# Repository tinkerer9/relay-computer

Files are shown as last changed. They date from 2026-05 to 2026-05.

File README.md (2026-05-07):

# Relay Computer
A relay computer that adds or subtracts two 4-bit numbers made for a Capstone project

## How to use
Power the computer with a 5V through the barrel jack on the top-right.

There are nine switches on the bottom left&mdash;these are the inputs.
The four on the top are the A3-A0 inputs, and the four on the bottom are the B3-B0 inputs.

On the the switch on the middle-right is the additon-subtraction selector.
Switch it up to add the two numbers, and down to subtract them.

## Bill of materials
Here is the BOM (bill of materials) for one of the computer, with links.
Prices are included (shipping not included) but always subject to change.

| Item | Variant | Quantity | Link | Price |
| :-: | :-: | :-: | :-: | :-: |
| Relays *(100x)* | SRD-05VDC-SLC | 20 | [AliExpress](https://www.aliexpress.us/item/3256805988664644.html) | $19.27 |
| Diodes *(100x)* | 1N4007 | 28 | [Amazon](https://www.amazon.com/dp/B0FC2CQF24) | $5.99 |
| LEDs | *red, 5mm* | 33 | | |
| Switches *(10x)* | MTS-102 | 9 | [Amazon](https://www.amazon.com/dp/B0799HC3VY) | $7.99 |
| Barrel Jack | *5.5mm OD* | 1 | | |
| Resistors | 220&ohm; | 33 | | |
| PCB *(5x)* | | 1 | *see [how to order](#how-to-order)* | $15.80 |
| **Total** | | **125** | | **$49.05** |

## How to order
Head to [JLCPCB](https://cart.jlcpcb.com/quote?stencilLayer=2&stencilWidth=140&stencilLength=210&plateType=1) and upload the gerber file at [`production.zip`](https://github.com/tinkerer9/relay-computer/raw/refs/heads/main/production.zip).

Use the default options for customizing your order.
Use this table for reference:

| Option | Selection |
| :-: | :-: |
| Base Material | FR-4 |
| Layers | 2 |
| Dimensions | 210 * 140 mm |
| PCB Qty | *you choose* |
| Product Type | Industrial/Consumer electronics |
| PCB Thickness | 1.6mm |
| PCB Color | *you choose* |

Select a build time and add the PCB to your cart.

For my order, the 5 PCBs costed **$15.80** and the shipping costed **&approx;$30**, plus tarrifs.
I ended up paying **&approx;$50**.
These prices are subject to change.

## Questions
For any questions about this project, feel free to create a [new issue](https://github.com/tinkerer9/relay-computer/issues/new) on this repository.

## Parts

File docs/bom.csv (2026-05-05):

Reference | Qty | Value | Footprint
D1-D4;D9-D16;D21-D24;D29-D36;D41-D44 | 28 | 1N4007 | Diode_THT:D_DO-41_SOD81_P7.62mm_Horizontal
D5-D8;D17-D20;D25-D28;D37-D40;D45-D52;D54-D62 | 33 | LED | LED_THT:LED_D5.0mm
H1-H4 | 4 | MountingHole_Pad | MountingHole:MountingHole_4.3mm_M4_Pad
J1 | 1 | Barrel_Jack_Switch | Connector_BarrelJack:BarrelJack_Horizontal
K1-K20 | 20 | SANYOU_SRD_Form_C | Relay_THT:Relay_SPDT_SANYOU_SRD_Series_Form_C
R1-R24;R26-R34 | 33 | 220 | Resistor_THT:R_Axial_DIN0207_L6.3mm_D2.5mm_P10.16mm_Horizontal
SW1-SW9 | 9 | SW_SPDT | Toggle_Switch:MTS-102

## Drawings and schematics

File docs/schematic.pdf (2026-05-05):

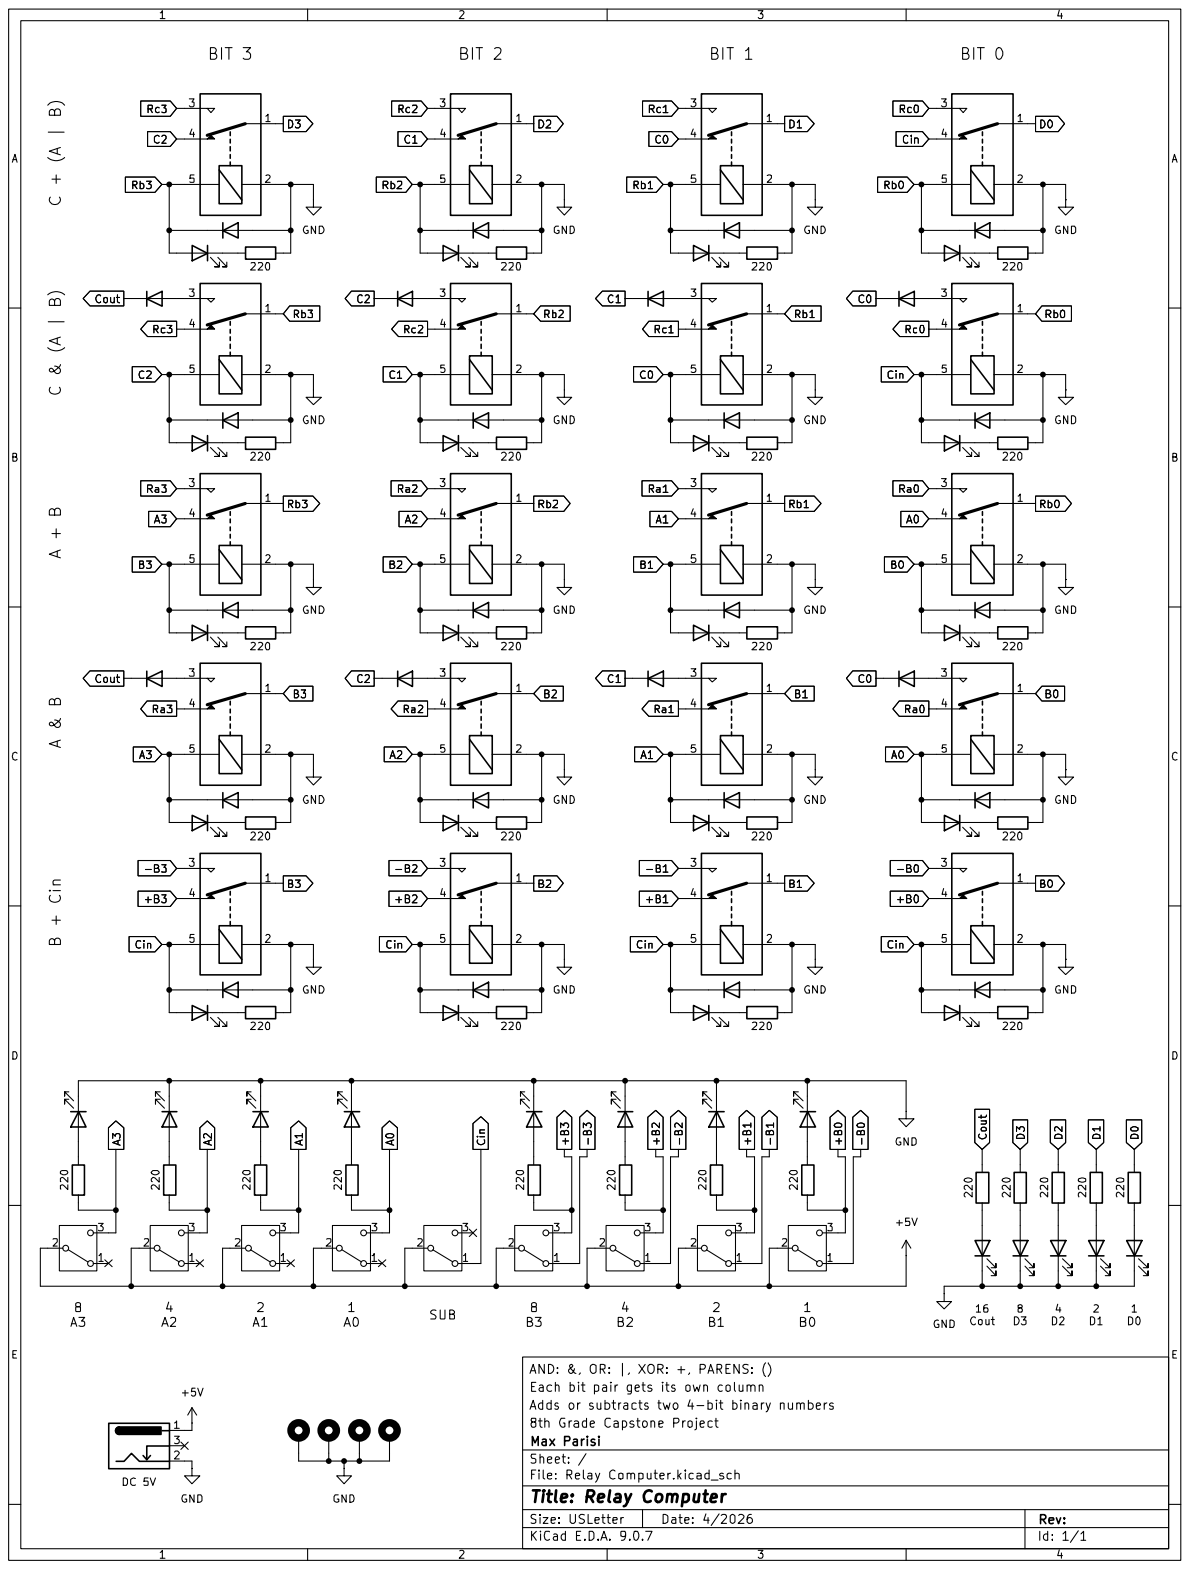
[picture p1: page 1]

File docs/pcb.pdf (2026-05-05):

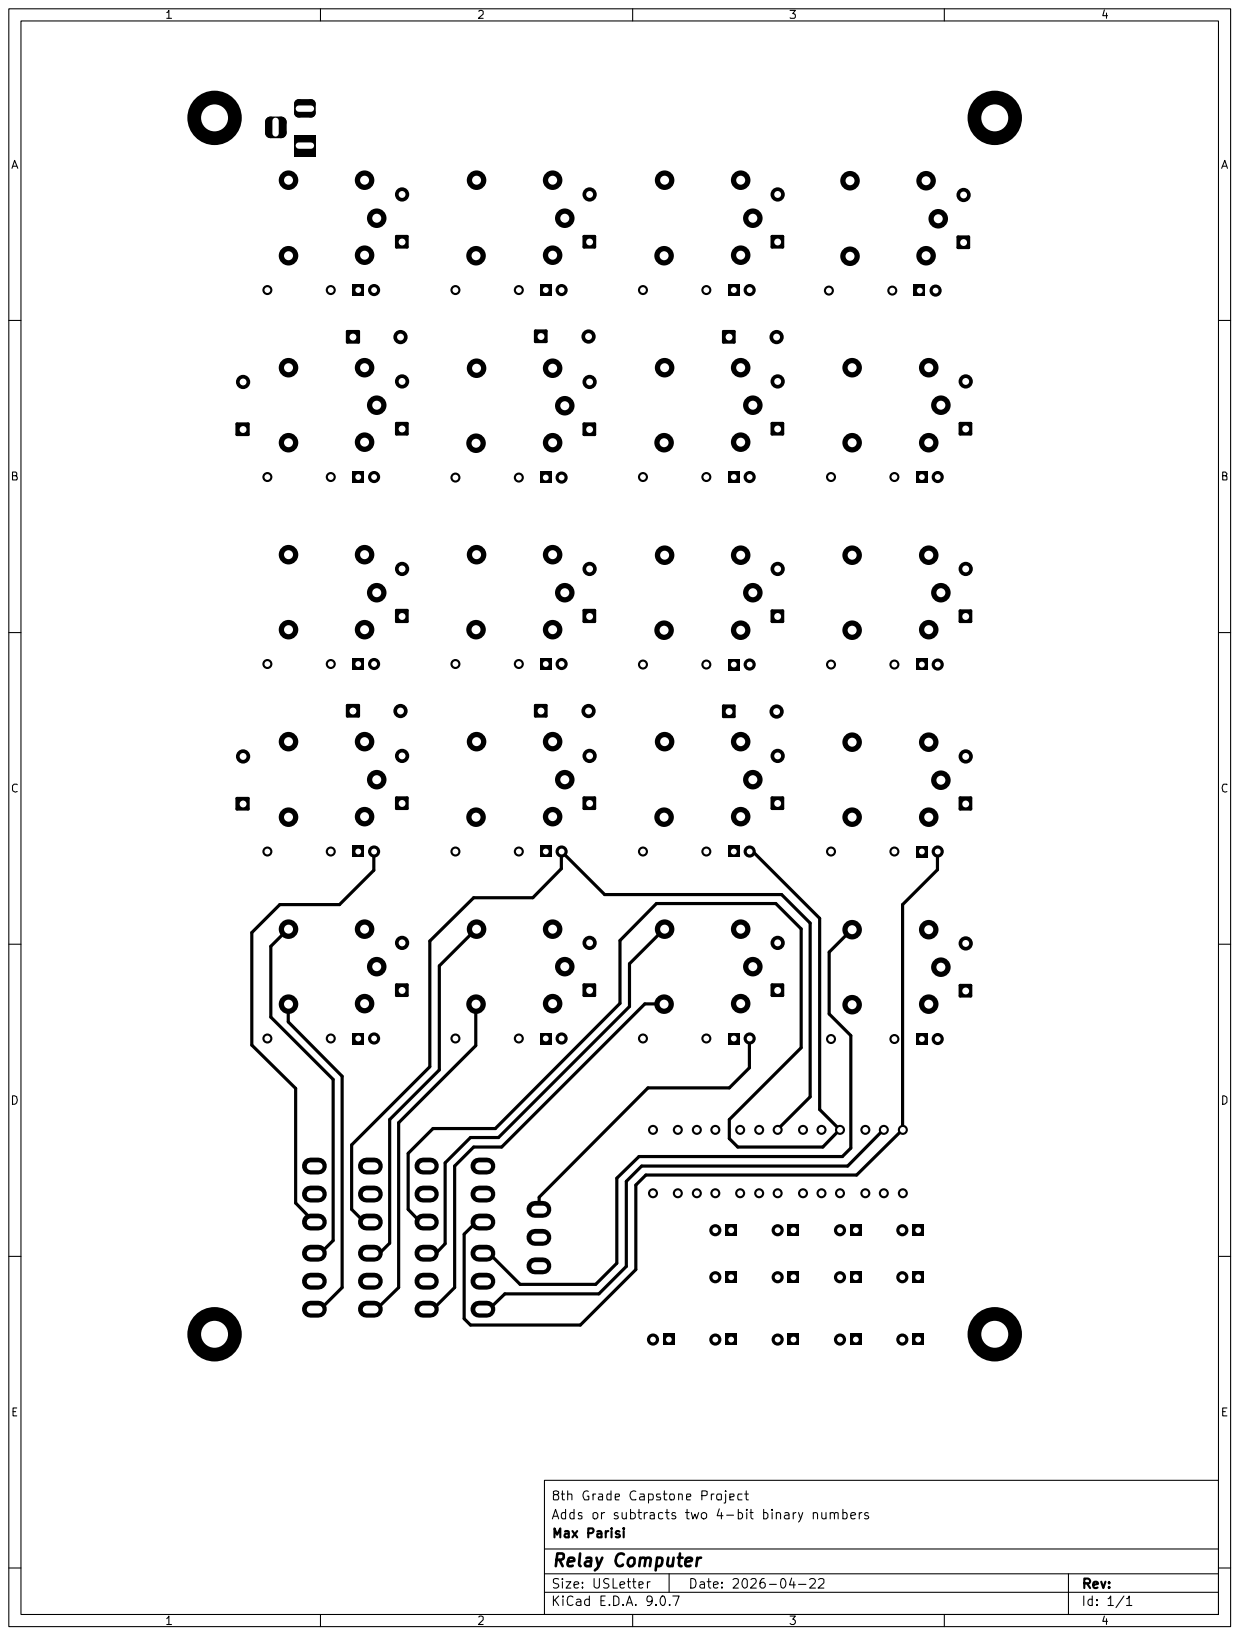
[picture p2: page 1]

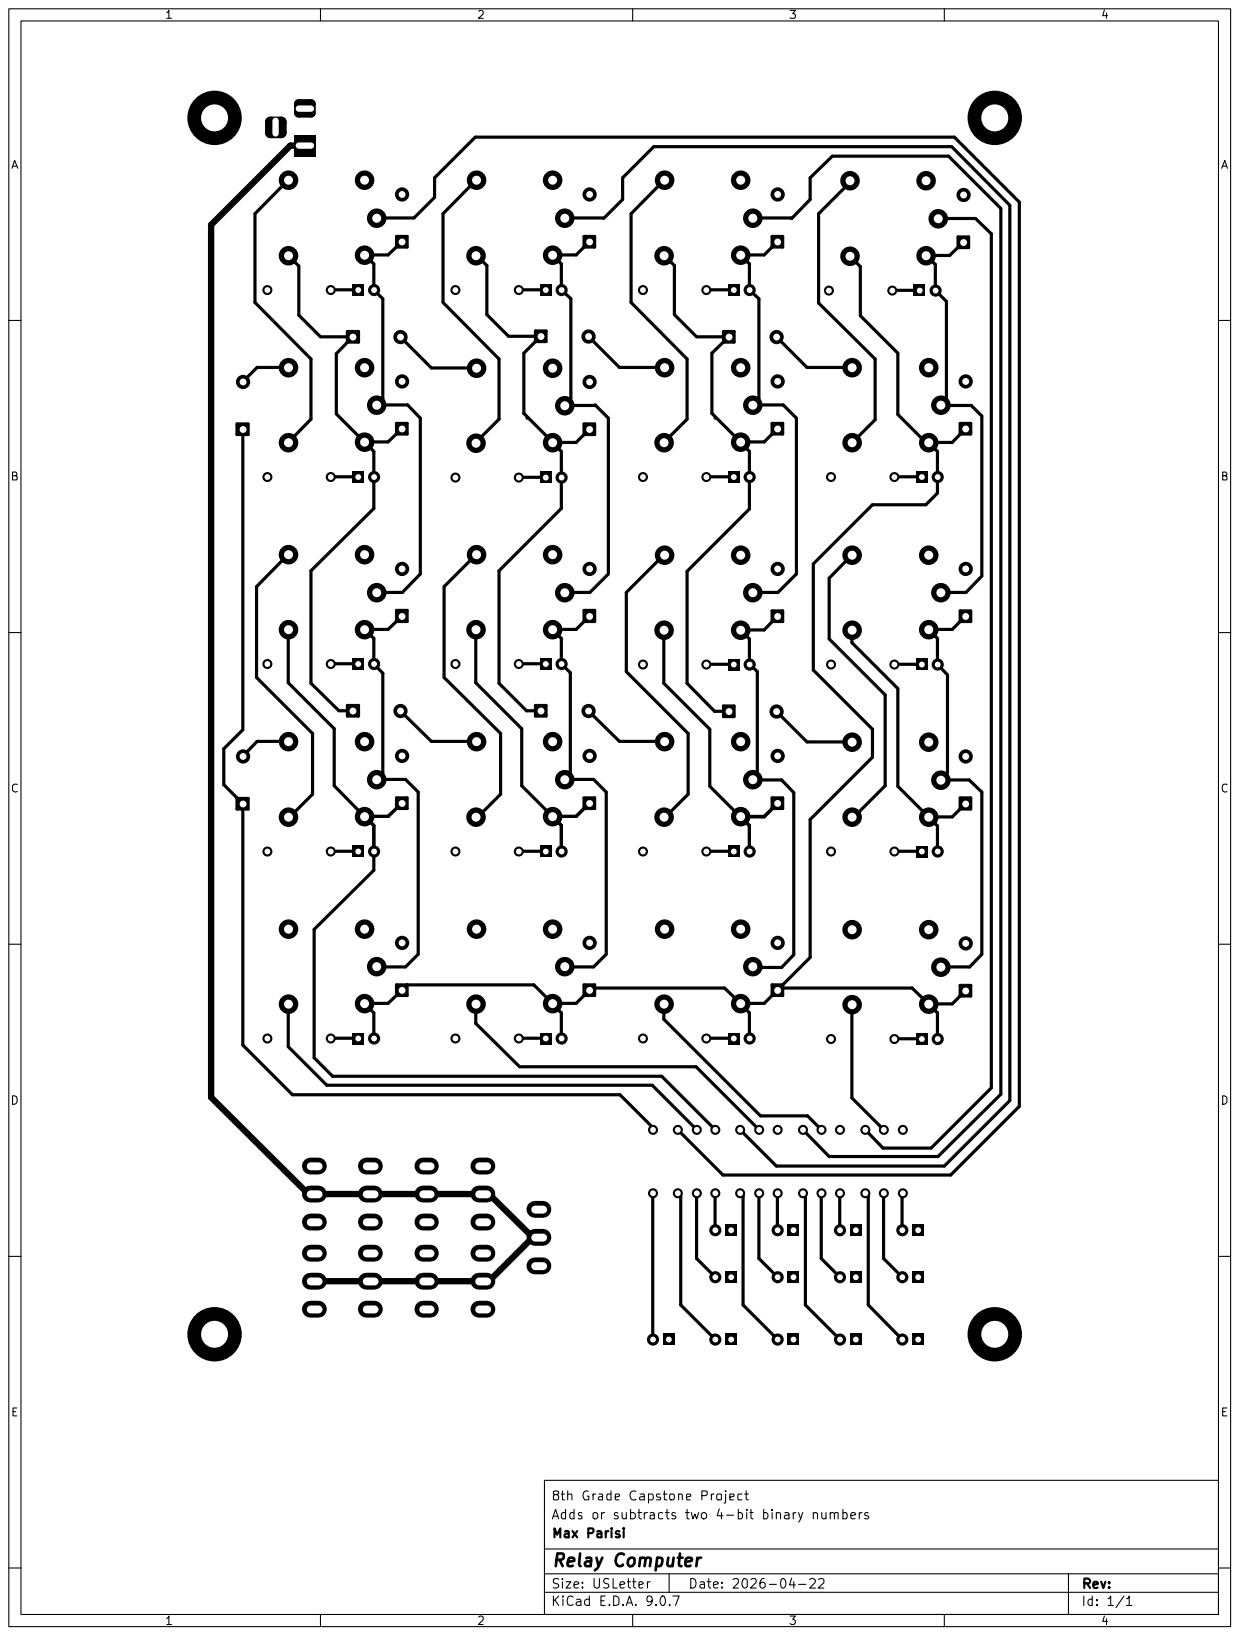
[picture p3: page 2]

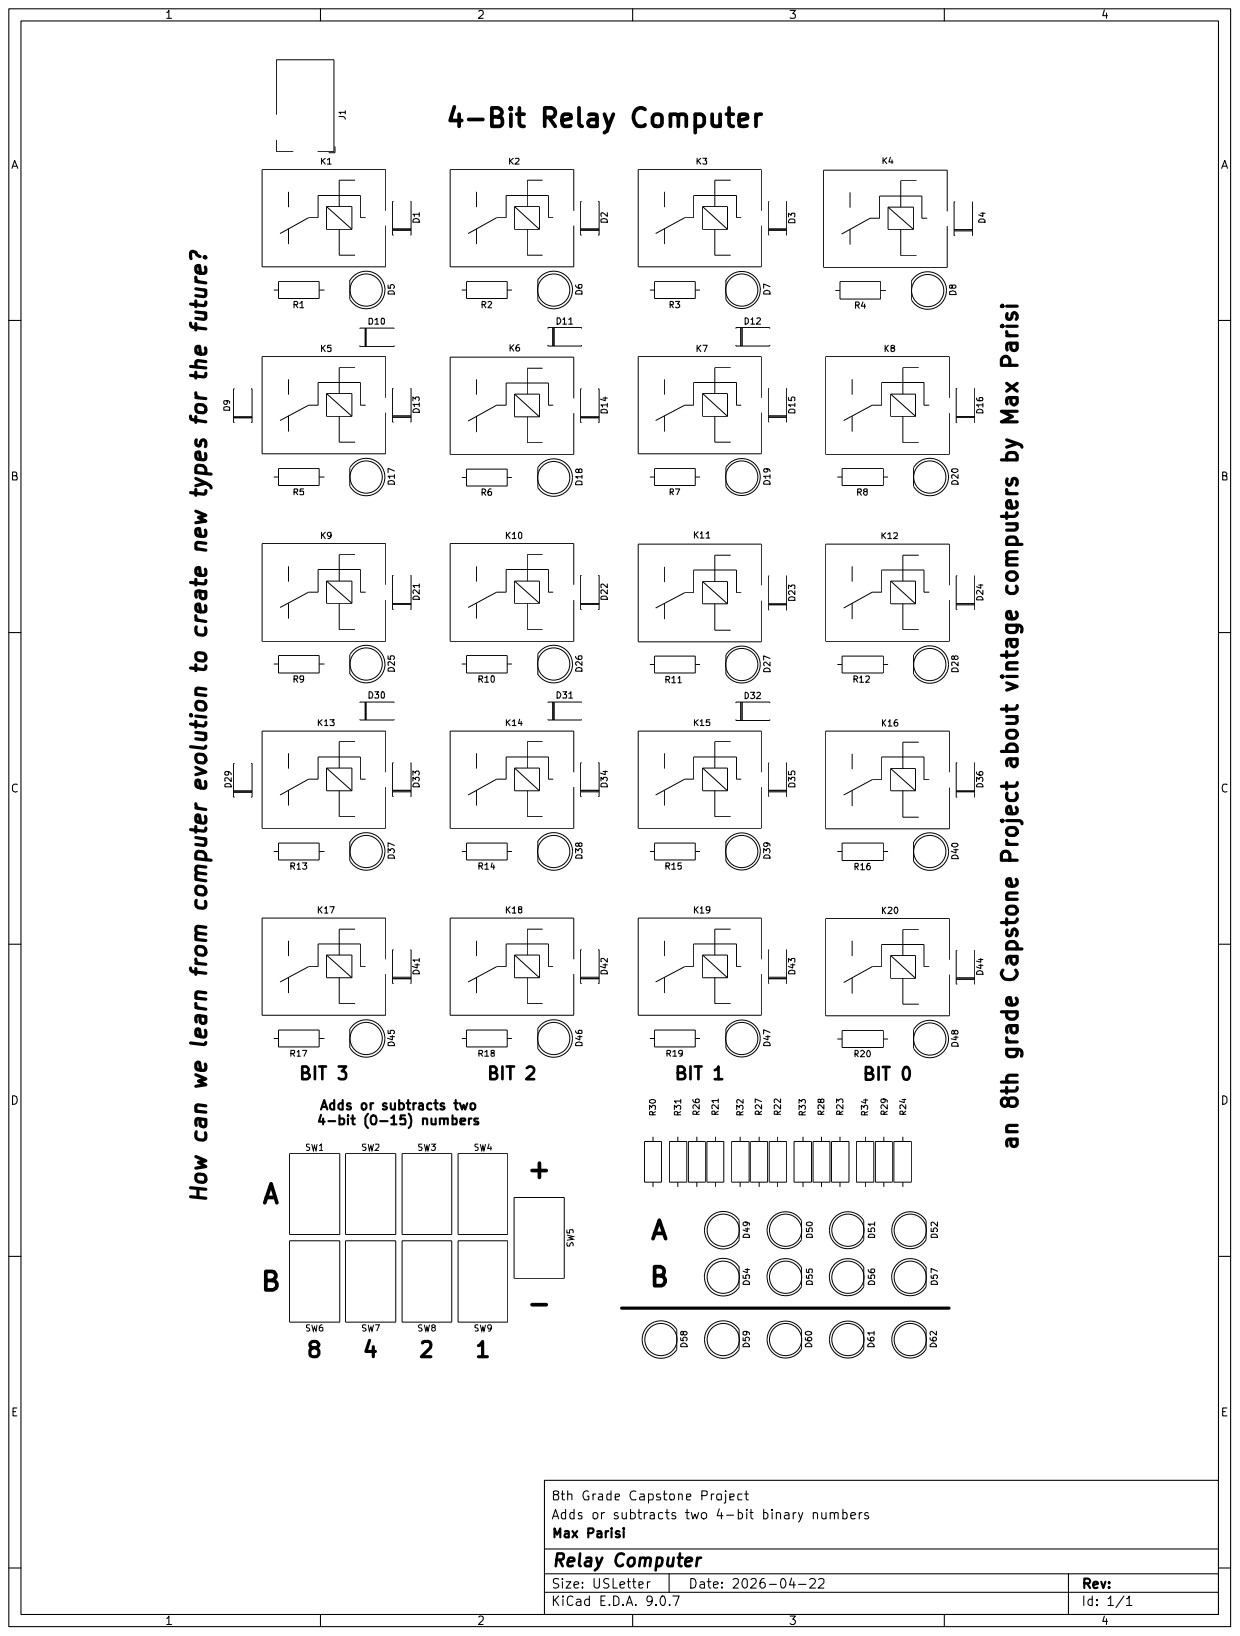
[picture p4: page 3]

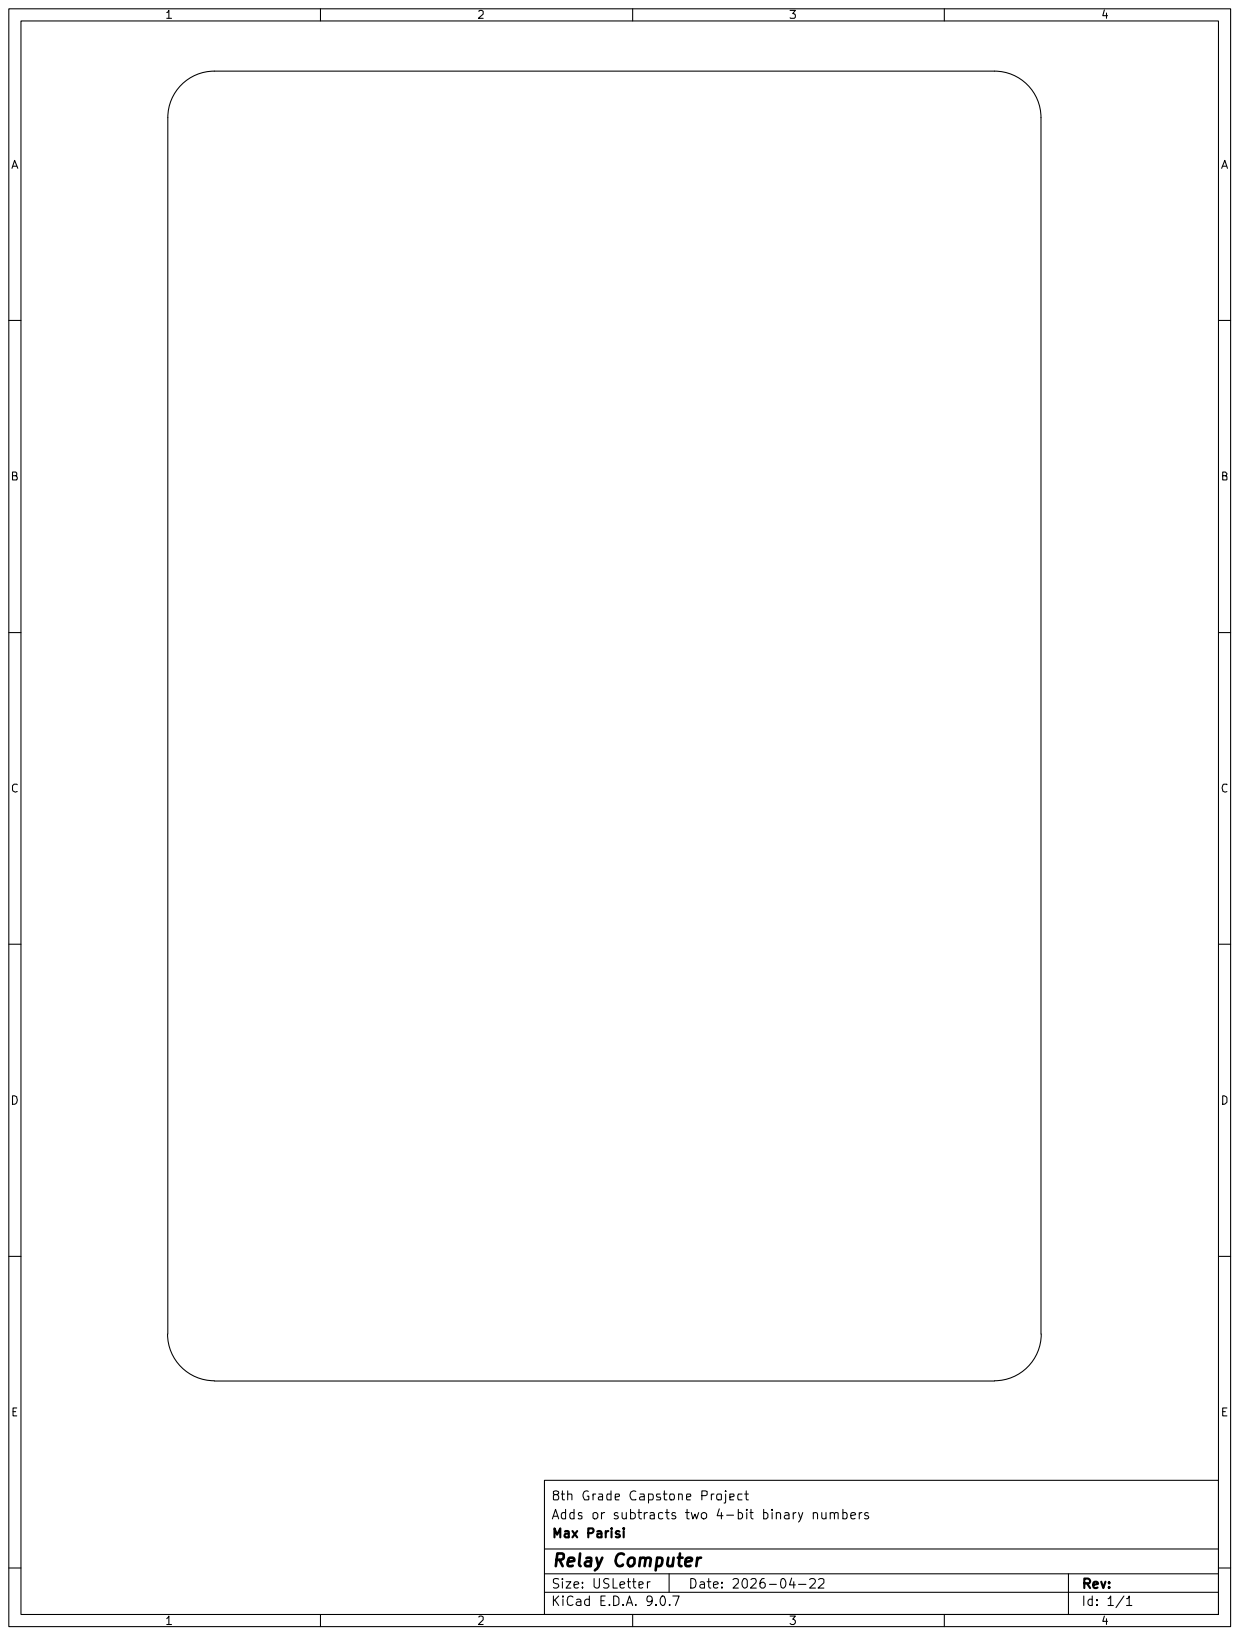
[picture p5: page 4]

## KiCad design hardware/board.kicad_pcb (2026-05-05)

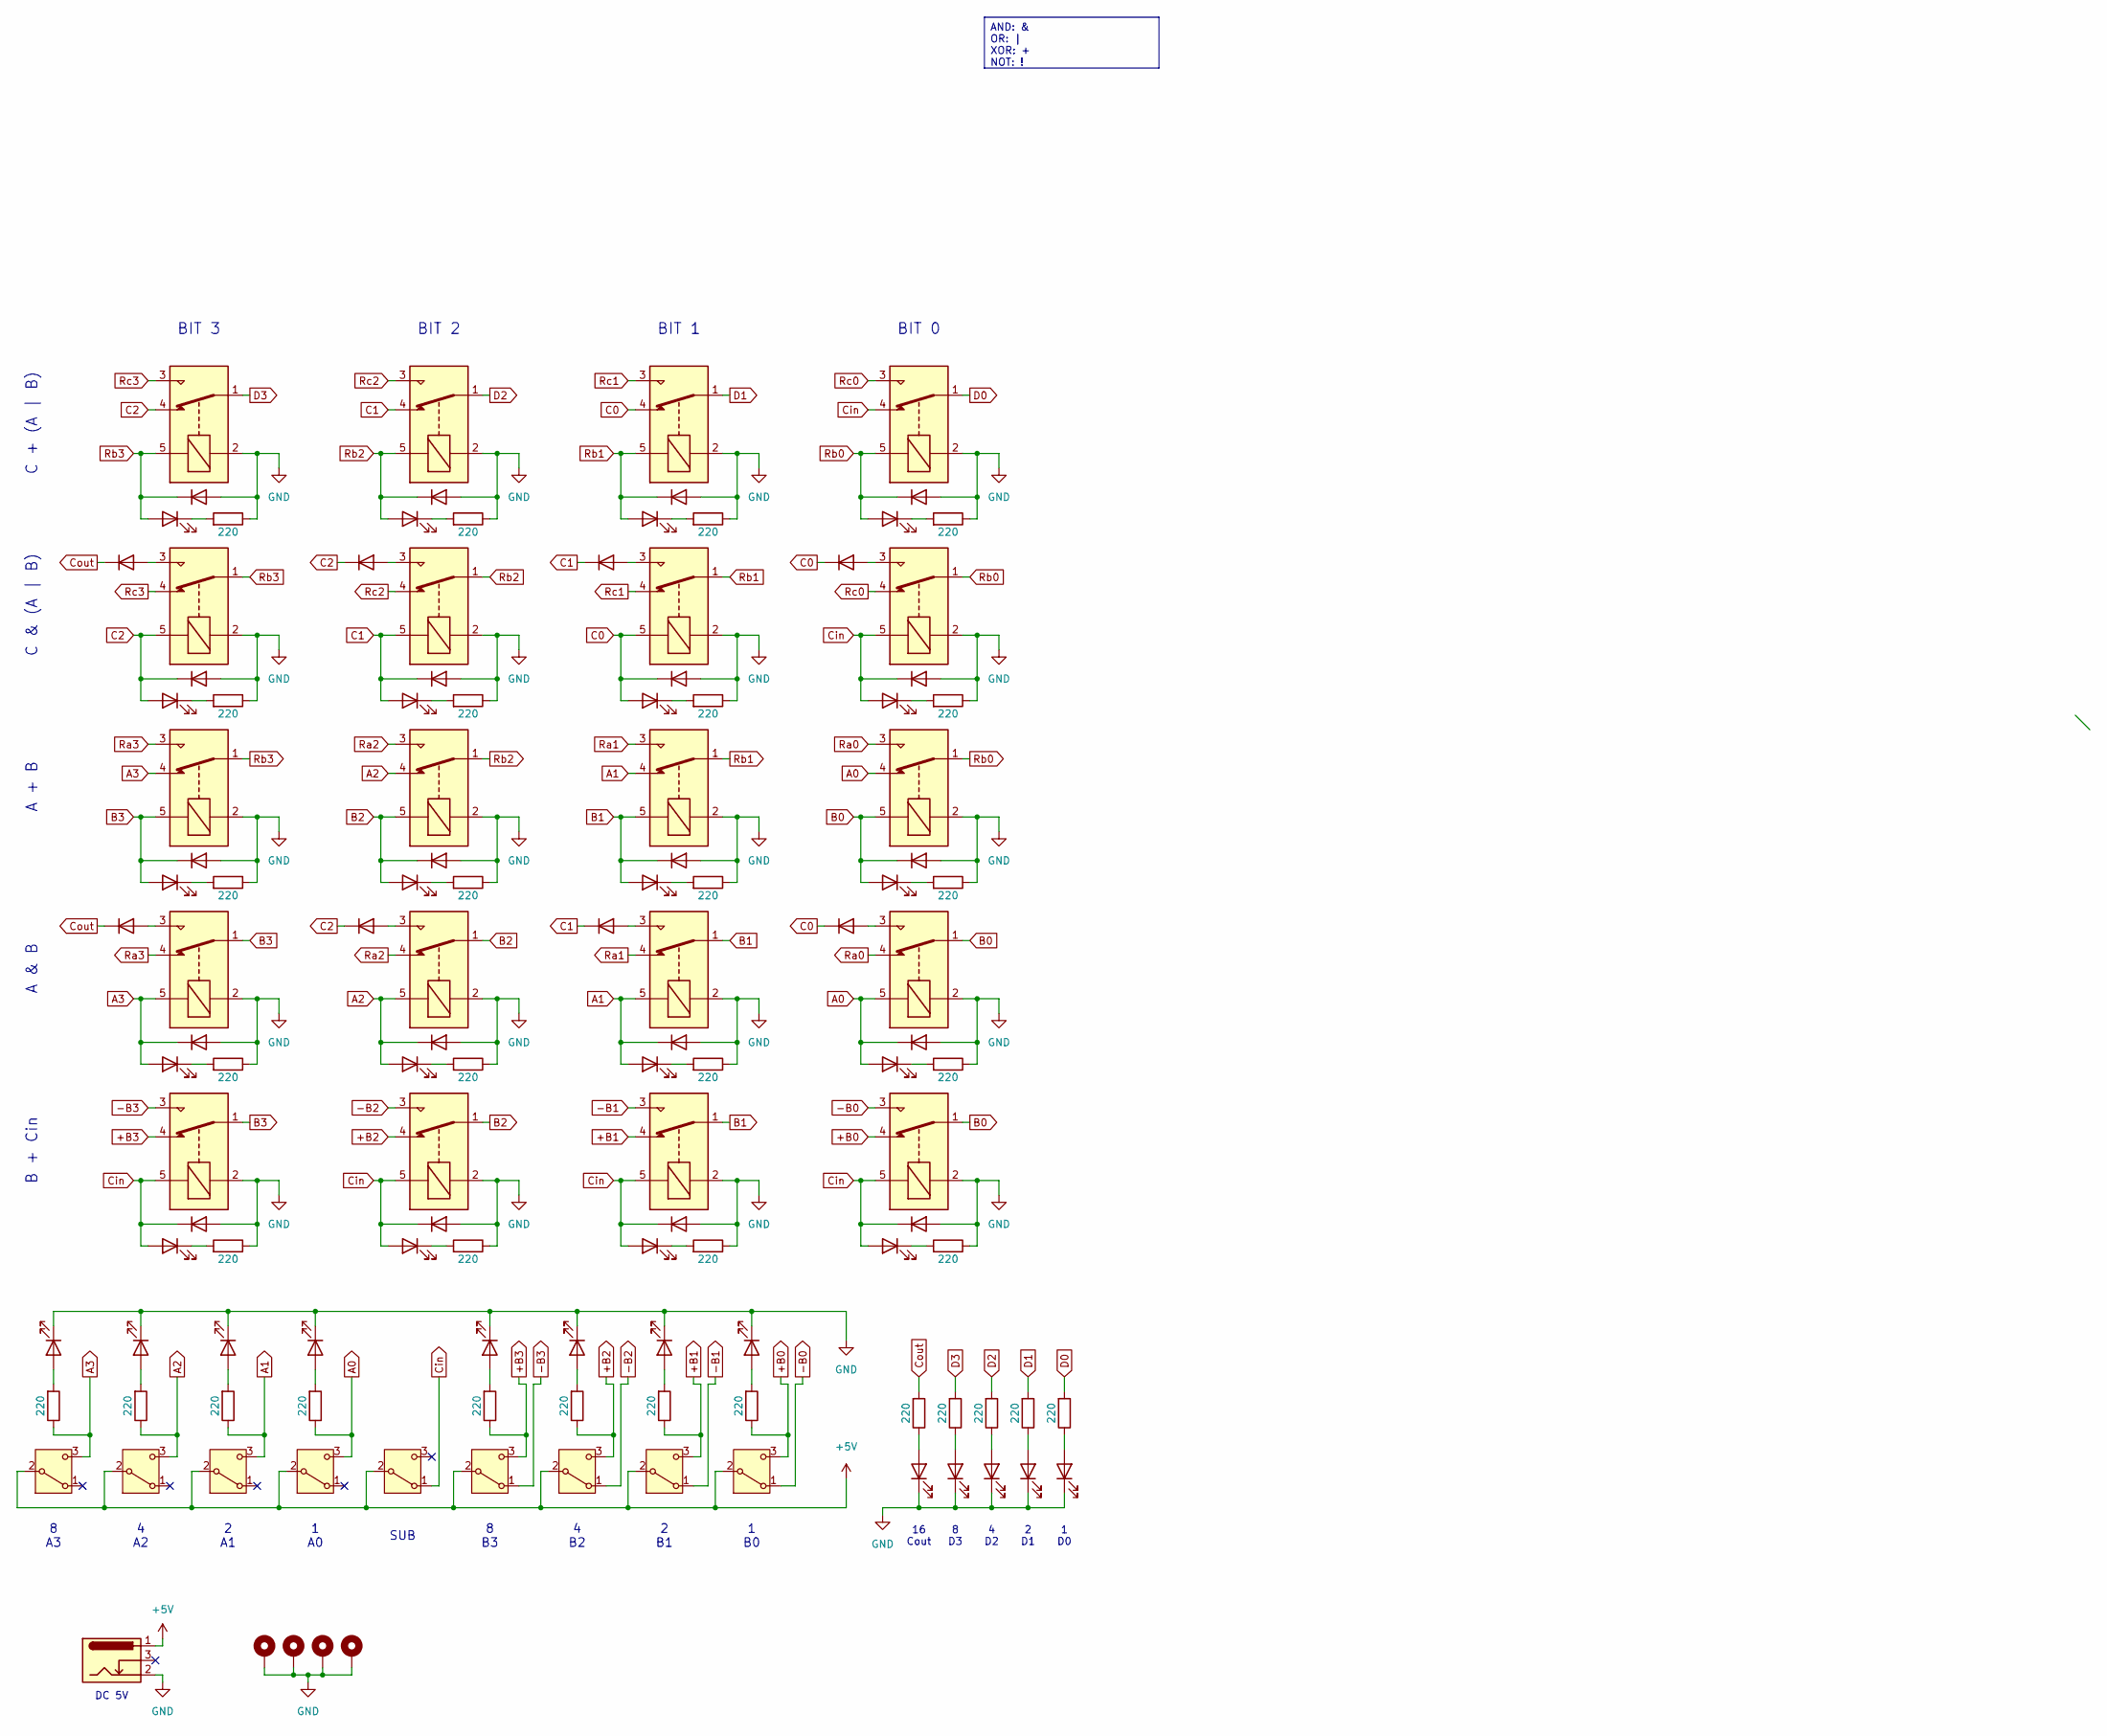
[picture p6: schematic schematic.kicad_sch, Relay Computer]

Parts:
D1, D2, D3, D4, D9, D10, D11, D12, D13, D14, D15, D16, D21, D22, D23, D24, D29, D30, D31, D32, D33, D34, D35, D36, D41, D42, D43, D44: 1N4007; D_DO-41_SOD81_P7.62mm_Horizontal
D5, D6, D7, D8, D17, D18, D19, D20, D25, D26, D27, D28, D37, D38, D39, D40, D45, D46, D47, D48, D49, D50, D51, D52, D54, D55, D56, D57, D58, D59, D60, D61, D62: LED; LED_D5.0mm
H1, H2, H3, H4: MountingHole_Pad; MountingHole_4.3mm_M4_Pad
J1: Barrel_Jack_Switch; BarrelJack_Horizontal
K1, K2, K3, K4, K5, K6, K7, K8, K9, K10, K11, K12, K13, K14, K15, K16, K17, K18, K19, K20: SANYOU_SRD_Form_C; Relay_SPDT_SANYOU_SRD_Series_Form_C
R1, R2, R3, R4, R5, R6, R7, R8, R9, R10, R11, R12, R13, R14, R15, R16, R17, R18, R19, R20, R21, R22, R23, R24, R26, R27, R28, R29, R30, R31, R32, R33, R34: 220; R_Axial_DIN0207_L6.3mm_D2.5mm_P10.16mm_Horizontal
SW1, SW2, SW3, SW4, SW5, SW6, SW7, SW8, SW9: SW_SPDT; MTS-102

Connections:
+5V: J1.1, SW1.2 (B), SW2.2 (B), SW3.2 (B), SW4.2 (B), SW5.2 (B), SW6.2 (B), SW7.2 (B), SW8.2 (B), SW9.2 (B)
+B0: K20.4, R29.1, SW9.3 (C)
+B1: K19.4, R28.1, SW8.3 (C)
+B2: K18.4, R27.1, SW7.3 (C)
+B3: K17.4, R26.1, SW6.3 (C)
-B0: K20.3, SW9.1 (A)
-B1: K19.3, SW8.1 (A)
-B2: K18.3, SW7.1 (A)
-B3: K17.3, SW6.1 (A)
A0: D36.1 (K), D40.2 (A), K12.4, K16.5, R24.1, SW4.3 (C)
A1: D35.1 (K), D39.2 (A), K11.4, K15.5, R23.1, SW3.3 (C)
A2: D34.1 (K), D38.2 (A), K10.4, K14.5, R22.1, SW2.3 (C)
A3: D33.1 (K), D37.2 (A), K9.4, K13.5, R21.1, SW1.3 (C)
B0: D24.1 (K), D28.2 (A), K12.5, K16.1, K20.1
B1: D23.1 (K), D27.2 (A), K11.5, K15.1, K19.1
B2: D22.1 (K), D26.2 (A), K10.5, K14.1, K18.1
B3: D21.1 (K), D25.2 (A), K9.5, K13.1, K17.1
C0: D12.1 (K), D15.1 (K), D19.2 (A), D32.1 (K), K3.4, K7.5
C1: D11.1 (K), D14.1 (K), D18.2 (A), D31.1 (K), K2.4, K6.5
C2: D10.1 (K), D13.1 (K), D17.2 (A), D30.1 (K), K1.4, K5.5
Cin: D16.1 (K), D20.2 (A), D41.1 (K), D42.1 (K), D43.1 (K), D44.1 (K), D45.2 (A), D46.2 (A), D47.2 (A), D48.2 (A), K4.4, K8.5, K17.5, K18.5, K19.5, K20.5, SW5.1 (A)
Cout: D9.1 (K), D29.1 (K), R30.2
D0: K4.1, R34.2
D1: K3.1, R33.2
D2: K2.1, R32.2
D3: K1.1, R31.2
GND: D1.2 (A), D2.2 (A), D3.2 (A), D4.2 (A), D13.2 (A), D14.2 (A), D15.2 (A), D16.2 (A), D21.2 (A), D22.2 (A), D23.2 (A), D24.2 (A), D33.2 (A), D34.2 (A), D35.2 (A), D36.2 (A), D41.2 (A), D42.2 (A), D43.2 (A), D44.2 (A), D49.1 (K), D50.1 (K), D51.1 (K), D52.1 (K), D54.1 (K), D55.1 (K), D56.1 (K), D57.1 (K), D58.1 (K), D59.1 (K), D60.1 (K), D61.1 (K), D62.1 (K), H1.1, H2.1, H3.1, H4.1, J1.2, K1.2, K2.2, K3.2, K4.2, K5.2, K6.2, K7.2, K8.2, K9.2, K10.2, K11.2, K12.2, K13.2, K14.2, K15.2, K16.2, K17.2, K18.2, K19.2, K20.2, R1.1, R2.1, R3.1, R4.1, R5.1, R6.1, R7.1, R8.1, R9.1, R10.1, R11.1, R12.1, R13.1, R14.1, R15.1, R16.1, R17.1, R18.1, R19.1, R20.1
unnamed: D5.1 (K), R1.2
unnamed: D6.1 (K), R2.2
unnamed: D7.1 (K), R3.2
unnamed: D8.1 (K), R4.2
unnamed: D9.2 (A), K5.3
unnamed: D10.2 (A), K6.3
unnamed: D11.2 (A), K7.3
unnamed: D12.2 (A), K8.3
unnamed: D17.1 (K), R5.2
unnamed: D18.1 (K), R6.2
unnamed: D19.1 (K), R7.2
unnamed: D20.1 (K), R8.2
unnamed: D25.1 (K), R9.2
unnamed: D26.1 (K), R10.2
unnamed: D27.1 (K), R11.2
unnamed: D28.1 (K), R12.2
unnamed: D29.2 (A), K13.3
unnamed: D30.2 (A), K14.3
unnamed: D31.2 (A), K15.3
unnamed: D32.2 (A), K16.3
unnamed: D37.1 (K), R13.2
unnamed: D38.1 (K), R14.2
unnamed: D39.1 (K), R15.2
unnamed: D40.1 (K), R16.2
unnamed: D45.1 (K), R17.2
unnamed: D46.1 (K), R18.2
unnamed: D47.1 (K), R19.2
unnamed: D48.1 (K), R20.2
unnamed: D49.2 (A), R21.2
unnamed: D50.2 (A), R22.2
unnamed: D51.2 (A), R23.2
unnamed: D52.2 (A), R24.2
unnamed: D54.2 (A), R26.2
unnamed: D55.2 (A), R27.2
unnamed: D56.2 (A), R28.2
unnamed: D57.2 (A), R29.2
unnamed: D58.2 (A), R30.1
unnamed: D59.2 (A), R31.1
unnamed: D60.2 (A), R32.1
unnamed: D61.2 (A), R33.1
unnamed: D62.2 (A), R34.1
Ra0: K12.3, K16.4
Ra1: K11.3, K15.4
Ra2: K10.3, K14.4
Ra3: K9.3, K13.4
Rb0: D4.1 (K), D8.2 (A), K4.5, K8.1, K12.1
Rb1: D3.1 (K), D7.2 (A), K3.5, K7.1, K11.1
Rb2: D2.1 (K), D6.2 (A), K2.5, K6.1, K10.1
Rb3: D1.1 (K), D5.2 (A), K1.5, K5.1, K9.1
Rc0: K4.3, K8.4
Rc1: K3.3, K7.4
Rc2: K2.3, K6.4
Rc3: K1.3, K5.4

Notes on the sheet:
BIT 3
2 B1
A & B
BIT 0
C + (A | B)
BIT 1
4 B2
8 D3
16 Cout
1 A0
1 B0
A + B
4 A2
DC 5V
8 B3
4 D2
2 A1
SUB
2 D1
C & (A | B)
8 A3
B + Cin
1 D0
BIT 2
AND: & OR: | XOR: + NOT: !

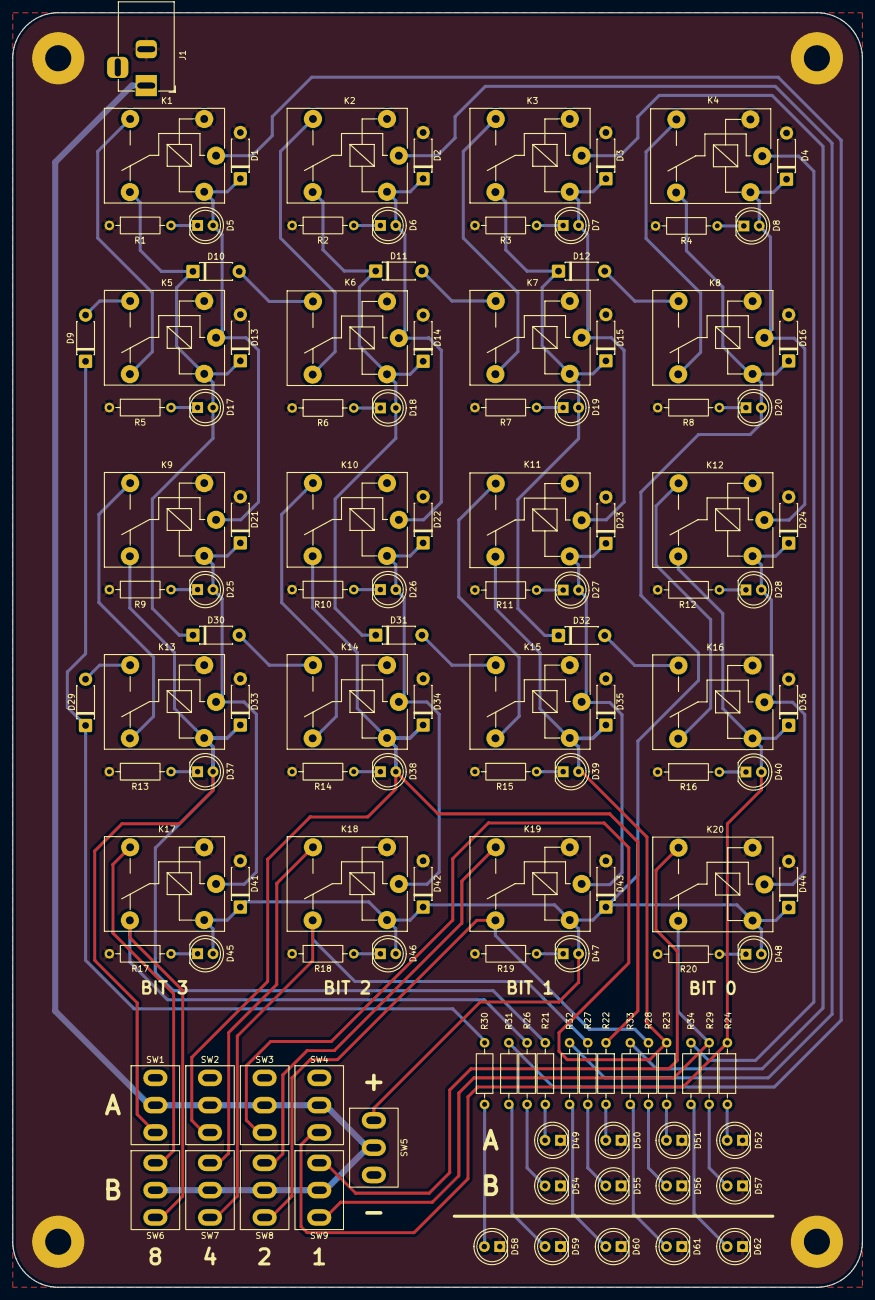
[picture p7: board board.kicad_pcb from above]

Board: 2 copper layers, 140.0 x 210.0 mm, 128 parts (0 on the bottom side), 80 nets.

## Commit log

2026-05-05 Add .gitignore for KiCad
2026-05-05 add BOM
2026-05-07 Fix formatting of PCB ordering note in README
